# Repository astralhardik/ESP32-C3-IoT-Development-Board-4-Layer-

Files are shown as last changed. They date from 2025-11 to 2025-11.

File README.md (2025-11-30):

# ESP32-C3 IoT Development Board (4-Layer)



## 📋 Project Overview

This repository contains the hardware design files (KiCad) for a custom **4-layer IoT Development Board** powered by the **ESP32-C3-WROOM-02** module. 

Designed this compact board is an all-in-one solution for environmental sensing and data logging. It integrates power management for LiPo batteries, a suite of sensors (Environmental, Light, Audio), and dual storage options (SD Card + External Flash), making it ideal for low-power edge computing applications.

<p align="center">
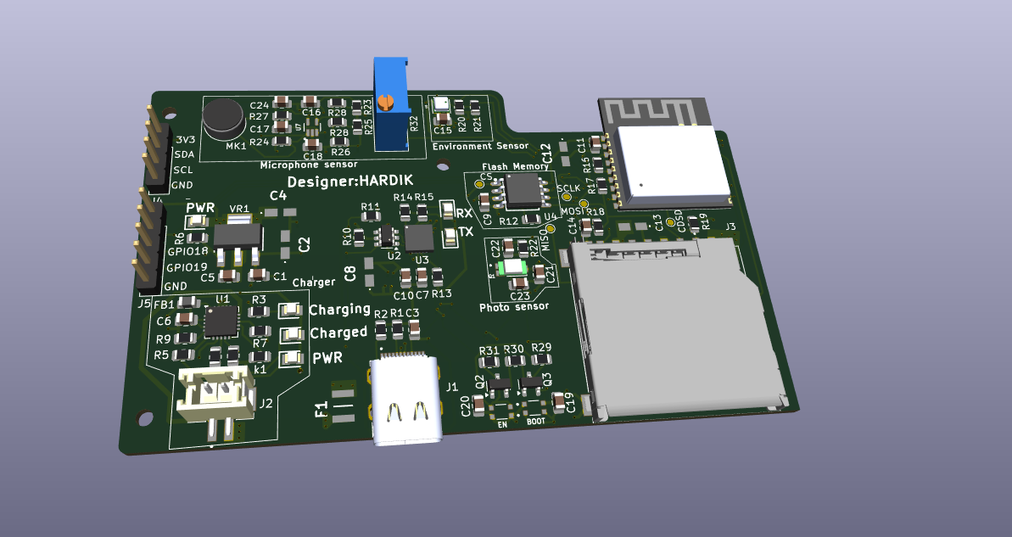
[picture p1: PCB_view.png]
3D Board View
  
</p>

## ✨ Key Features

*   **Microcontroller**: ESP32-C3-WROOM-02 (RISC-V 32-bit, WiFi 4 + Bluetooth 5 LE).
*   **4-Layer PCB**: Optimized stack-up for signal integrity and compact routing.
*   **Power System**: 
    *   **USB-C** for power and programming.
    *   **MCP73871** Li-Ion/Li-Poly Battery Charger with System Load Sharing (allows simultaneous charging and system operation).
    *   **LM1117-3.3** LDO for stable 3.3V regulation.
*   **Onboard Sensors**:
    *   **BME280**: Temperature, Humidity, and Barometric Pressure (I2C).
    *   **MAX4466**: Electret Microphone with Preamplifier (Analog Output).
    *   **TEMT6000**: Ambient Light Sensor (Analog Photo-transistor).
*   **Storage**:
    *   **MicroSD Card Slot** (SPI mode).
    *   **W25Q32** 32M-bit (4MB) External SPI Flash for logging/OTA.
*   **Connectivity**:
    *   **CP2102N** USB-to-UART Bridge with Auto-Program/Reset circuit (DTR/RTS logic).
    *   **I2C Header**: JST/Pin header for external OLED displays or sensors.

## 🔧 Hardware Specifications

| Component | Part Number | Interface | Description |
|---|---|---|---|
| **MCU Module** | ESP32-C3-WROOM-02-H4 | UART/SPI/I2C | Core processor, 4MB integrated flash |
| **USB Bridge** | CP2102N | USB 2.0 | USB to Serial converter |
| **Env. Sensor** | BME280 | I2C (Add: 0x76) | Precision Temp/Hum/Press |
| **Audio Amp** | MAX4466 | Analog (ADC) | Mic preamp with adjustable gain |
| **Light Sensor** | TEMT6000 | Analog (ADC) | Visible light spectrum sensor |
| **Charger** | MCP73871 | - | 1A Battery charger with Power Path |
| **Ext. Flash** | W25Q32JV | SPI | Additional 32Mbit storage |

## 🔌 Pinout & Interfaces

### User Interface (UI)
*   **Boot Button (SW1)**: Connected to GPIO9 (Strapping pin).
*   **Reset Button (SW2)**: Connected to EN (Enable).
*   **LED Indicators**: 
    *   Charging (Red)
    *   Charged (Green)
    *   Power/User (Blue)

### Expansion Headers
*   **J4 (I2C)**: `3V3`, `SDA`, `SCL`, `GND` - Designed for 0.96" OLED displays.
*   **J5 (GPIO)**: Breakout for spare GPIOs (GPIO8, GPIO18, GPIO19).

## 🛠️ Schematics

### Power Management
The power stage uses the **MCP73871** to manage USB and Battery power seamlessy. An **LM1117-3.3** provides the system voltage.

### Sensor Array
The board features a BME280 for environment data, a MAX4466 for audio processing, and a TEMT6000 for light detection.

### MCU & Storage
The ESP32-C3 is the heart of the board, interfacing with the SD Card and Flash memory via SPI.

## 🚀 Getting Started

1.  **Clone the repository**:
    ```
    git clone https://github.com/yourusername/ESP32-C3-IoT-Board.git
    ```
2.  **Open the Hardware Design**:
    *   Install [KiCad 9.0+](https://www.kicad.org/).
    *   Open `ESP32 project/ESP32 project.kicad_pro`.
3.  **Firmware Development**:
    *   The board uses the **CP2102N** bridge. Ensure drivers are installed.
    *   **PlatformIO / Arduino IDE**: Select board **"ESP32C3 Dev Module"**.
    *   **Auto-Upload**: The board includes the standard transistor reset logic, so no manual button pressing is required to upload code.

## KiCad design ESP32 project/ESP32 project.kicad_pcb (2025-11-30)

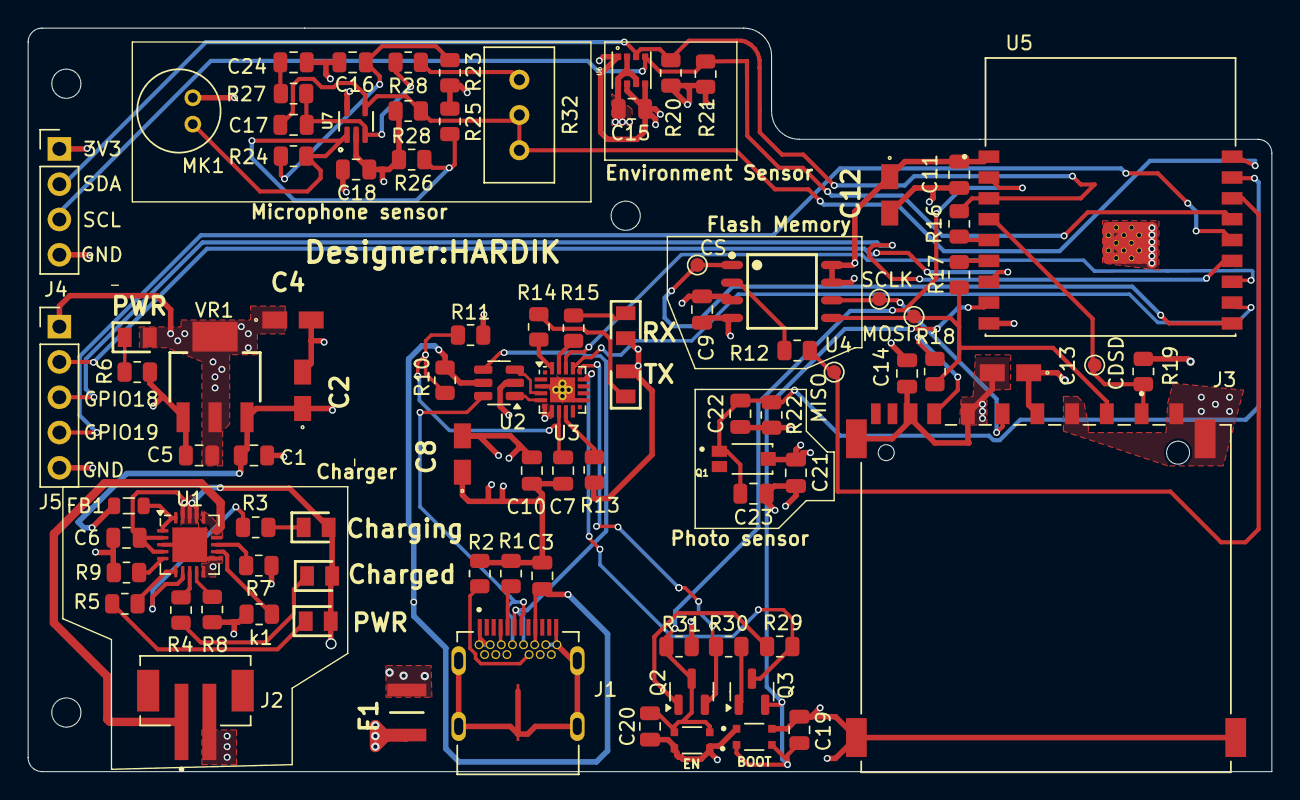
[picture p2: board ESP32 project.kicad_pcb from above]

Board: 4 copper layers, 89.5 x 53.5 mm, 90 parts (0 on the bottom side), 60 nets.

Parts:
BOOT: Boot; SW_USLPT2819DT2TR
C1, C3, C5, C10, C15, C16, C17, C18, C19, C21: 0.1u; C_0805_2012Metric
C2, C4: 10u; T491A
C6, C20: 1u; C_0805_2012Metric
C7: 1uf; C_0805_2012Metric
C8: 4.7u; T491A
C9, C11, C14: 0.1U; C_0805_2012Metric
C12, C13: 10U; T491A
C22, C23: 10n; C_0805_2012Metric
C24: 10u; C_0805_2012Metric
CDSD: Test CS_SD; TestPoint_Pad_D1.0mm
CS: Test CS; TestPoint_Pad_D1.0mm
Charged: LTST-C170GKT; LEDC2012X120N
Charging: LTST-C170TBKT; LEDC2012X120N
EN: Reset; SW_USLPT2819DT2TR
F1: 0ZCH0110AF2E; FUSC3226X100N
FB1: FerriteBead; L_0805_2012Metric
J1: SS-52400-002; BELFUSE_SS-52400-002
J2: B2B-PH-SM4-TB; JST_B2B-PH-SM4-TB
J3: GSD090012SEU; AMPHENOL_GSD090012SEU
J4: Conn_01x04_Pin; PinHeader_1x04_P2.54mm_Vertical
J5: Conn_01x05_Pin; PinHeader_1x05_P2.54mm_Vertical
MISO: Test MISO; TestPoint_Pad_D1.0mm
MK1: CMC-5042PF-AC; CUI_CMC-5042PF-AC
MOSI: Test MOSI; TestPoint_Pad_D1.0mm
PWR: LTST-C170KRKT; LEDC2012X120N
PWR#2: LTST-C170KRKT; LEDC2012X120N
Q1: TEMT6000X01; TRANS_TEMT6000X01
Q2, Q3: BC817; SOT-23
R1, R2: 5k1; R_0805_2012Metric
R3, R4, R5, R6, R14, R15: 470; R_0805_2012Metric
R7: 2k; R_0805_2012Metric
R8, R9, R22: 10k; R_0805_2012Metric
R10: 22k1; R_0805_2012Metric
R11: 47k5; R_0805_2012Metric
R12, R16, R17, R18: 50; R_0805_2012Metric
R13, R27: 1k; R_0805_2012Metric
R19, R29, R30, R31: 10K; R_0805_2012Metric
R20, R21: 4k7; R_0805_2012Metric
R23, R24: 2K; R_0805_2012Metric
R25, R26: 1M; R_0805_2012Metric
R28: 100K; R_0805_2012Metric
R28#2: 22k; R_0805_2012Metric
R32: 35WR100KLFTR; Potentiometer_Bourns_3296W_Vertical
RX: LTST-C170KRKT; LEDC2012X120N
SCLK: Test SCLK; TestPoint_Pad_D1.0mm
TX: LTST-C170GKT; LEDC2012X120N
U1: MCP73871; QFN-20-1EP_4x4mm_P0.5mm_EP2.5x2.5mm
U2: USBLC6-2SC6; SOT-23-6
U3: CP2102N-Axx-xQFN20; SiliconLabs_QFN-20-1EP_3x3mm_P0.5mm_EP1.8x1.8mm_ThermalVias
U4: W25Q32JVSSIQ; SOIC127P790X216-8N
U5: ESP32-C3-WROOM-02-H4; MODULE_ESP32-C3-WROOM-02-H4
U6: BME280; PSON65P250X250X100-8N
U7: MAX4466EXK; SOT65P210X110-5N
VR1: LM1117MPX-3.3; VREG_LM1117MPX-3.3
k1: 20k; R_0805_2012Metric

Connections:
+3.3V: C4.1, C5.1, C8.2, C9.1, C10.2, C11.1, C12.1, C13.1, C14.1, C15.1, C18.1, C21.2, J3.4 (VDD1), J4.1, J5.1, PWR#2.2 (A), Q1.3, R13.1, R19.1, R20.1, R21.1, R23.1, R25.1, R31.1, RX.2 (A), TX.2 (A), U3.6 (VDD), U3.7 (VREGIN), U4.3 (~WP(IO2)), U4.7 (~HOLD/~RESET(IO3)), U4.8 (VCC), U5.1 (3V3), U6.2 (CSB), U6.6 (VDDIO), U6.8 (VDD), U7.5 (VCC), VR1.2 (VOUT_2), VR1.4 (VOUT_4)
+5V: C1.1, C2.1, FB1.2, VR1.3 (VIN)
/+5v_USB: C6.1, Charged.2 (A), Charging.2 (A), F1.2, PWR.2 (A), U1.2 (VPCC), U1.4 (PROG2), U1.17 (CE), U1.18 (IN), U1.19 (IN)
/ESP32-C3-02/BOOT: BOOT.3 (B0), BOOT.4 (B1), C19.1, Q3.2 (E), U5.8 (IO9)
/ESP32-C3-02/CD_SD: CDSD.1, J3.1 (CD/DAT3), R19.2, U5.4 (IO5)
/ESP32-C3-02/CS: CS.1, U4.1 (~CS), U5.10 (IO10)
/ESP32-C3-02/CTS: Q3.3 (C), R29.1, U3.15 (~CTS)
/ESP32-C3-02/EN: C20.1, EN.3 (B0), EN.4 (B1), Q2.3 (C), R31.2, U5.2 (EN)
/ESP32-C3-02/GPIO8: J5.2, U5.7 (IO8)
/ESP32-C3-02/GPIO18: J5.3, U5.13 (IO18)
/ESP32-C3-02/GPIO19: J5.4, U5.14 (IO19)
/ESP32-C3-02/MIC_OUT: C17.2, R28.2, R32.1, R32.2, U5.18 (IO0), U7.4 (OUT)
/ESP32-C3-02/MISO_DO: MISO.1, R12.2, U5.16 (IO2)
/ESP32-C3-02/MOSI_DI: J3.2 (CMD), MOSI.1, R17.1, R18.1, U4.5 (DI(IO0))
/ESP32-C3-02/PHOTO_C: C22.1, C23.1, Q1.1, R22.1, U5.17 (IO1)
/ESP32-C3-02/RTS: Q2.2 (E), R30.1, U3.16 (~RTS)
/ESP32-C3-02/RX_TX: U3.17 (RXD), U5.11 (RXD)
/ESP32-C3-02/SCL: J4.3, R21.2, U5.15 (IO3), U6.4 (SCK)
/ESP32-C3-02/SCLK: J3.5 (CLK), SCLK.1, U4.6 (CLK)
/ESP32-C3-02/SDA: J4.2, R16.1, R20.2, U5.3 (IO4), U6.3 (SDI)
/ESP32-C3-02/TX_RX: U3.18 (TXD), U5.12 (TXD)
/ESP32-C3-02/USB_D+: U2.3 (I/O2), U3.4 (D+)
/ESP32-C3-02/USB_D-: U2.1 (I/O1), U3.5 (D-)
/USB_DN: J1.A7 (DN1), J1.B7 (DN2), U2.6 (I/O1)
/USB_DP: J1.A6 (DP1), J1.B6 (DP2), U2.4 (I/O2)
/VBAT: J2.1, U1.14 (V_{BAT}), U1.15 (V_{BAT}), U1.16 (V_{BAT_SENSE})
/vBUS: C3.1, F1.1, J1.A4 (VBUSA1), J1.A9 (VBUSA2), J1.B4 (VBUSB1), J1.B9 (VBUSB2), R10.1, U2.5 (VBUS)
GND: BOOT.1 (A0), BOOT.2 (A1), C1.2, C2.2, C3.2, C4.2, C5.2, C6.2, C7.2, C8.1, C9.2, C10.1, C11.2, C12.2, C13.2, C14.2, C15.2, C16.1, C18.2, C19.2, C20.2, C21.1, C22.2, C23.2, C24.1, EN.1 (A0), EN.2 (A1), J1.A1 (GNDA1), J1.A12 (GNDA2), J1.B1 (GNDB1), J1.B12 (GNDB2), J1.G1 (GND/SHIELD), J1.G2 (GND/SHIELD), J1.G3 (GND/SHIELD), J1.G4 (GND/SHIELD), J1.S1 (GND/SHIELD), J1.S2 (GND/SHIELD), J1.S3 (GND/SHIELD), J1.S4 (GND/SHIELD), J2.2, J3.3 (VSS1), J3.6 (VSS2), J3.8 (DAT1), J3.9 (DAT2), J3.G1 (SHIELD_GND), J3.G2 (SHIELD_GND), J3.G3 (SHIELD_GND), J3.G4 (SHIELD_GND), J4.4, J5.5, MK1.GND, R1.2, R2.2, R6.2, R7.1, R8.2, R9.1, R11.2, R22.2, R26.2, R28.1, U1.3 (SEL), U1.10 (V_{SS}), U1.11 (V_{SS}), U1.21 (V_{SS}), U2.2 (GND), U4.4 (GND), U5.9 (GND), U5.19 (GND), U5.20 (GND), U5.21 (GND), U5.22 (GND), U5.23 (GND), U5.24 (GND), U5.25 (GND), U5.26 (GND), U5.27 (GND), U5.28 (GND), U5.29 (GND), U5.30 (GND), U5.31 (GND), U5.32 (GND), U5.33 (GND), U5.34 (GND), U5.35 (GND), U5.36 (GND), U5.37 (GND), U5.38 (GND), U5.39 (GND), U6.1 (GND), U6.5 (SDO), U6.7 (GND), U7.2 (GND), VR1.1 (GND), k1.1
unnamed: C16.2, R23.2, R24.1
unnamed: C24.2, R27.1
unnamed: FB1.1, U1.1 (OUT), U1.20 (OUT)
unnamed: J1.A5 (CC1), R1.1
unnamed: J1.B5 (CC2), R2.1
unnamed: J3.7 (DAT0), R18.2
unnamed: Charging.1 (K), R3.1
unnamed: PWR#2.1 (K), R6.1
unnamed: Charged.1 (K), R4.1
unnamed: PWR.1 (K), R5.1
unnamed: R14.1, TX.1 (K)
unnamed: R15.1, RX.1 (K)
unnamed: Q2.1 (B), R29.2
unnamed: Q3.1 (B), R30.2
unnamed: R28#2.1, R32.3
unnamed: R7.2, U1.13 (PROG1)
unnamed: U1.12 (PROG3), k1.2
unnamed: R4.2, U1.8 (STAT1/~LBO)
unnamed: R3.2, U1.7 (STAT2)
unnamed: R9.2, U1.5 (THERM)
unnamed: R5.2, U1.6 (~PG)
unnamed: R8.1, U1.9 (~TE)
unnamed: U3.3 (GND), U3.12 (GND), U3.21 (GND)
unnamed: C7.1, R10.2, R11.1, U3.8 (VBUS)
unnamed: R13.2, U3.9 (~RST)
unnamed: R15.2, U3.19 (~RXT/GPIO.3)
unnamed: R14.2, U3.20 (~TXT/GPIO.2)
unnamed: R12.1, U4.2 (DO(IO1))
unnamed: R16.2, U5.5 (IO6)
unnamed: R17.2, U5.6 (IO7)
unnamed: MK1.OUT, R24.2, R25.2, R26.1, U7.1 (IN+)
unnamed: C17.1, R27.2, R28#2.2, U7.3 (IN-)

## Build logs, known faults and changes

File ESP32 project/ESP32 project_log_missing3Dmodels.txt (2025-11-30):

[('C8', 'D:\\kicad\\ESP32-IOT 4 Layer PCB\\ESP32 project\\T491A106K010AT7280.stp'), ('LED4', 'D:\\kicad\\ESP32-IOT 4 Layer PCB\\ESP32 project\\LTST-C170KRKT.stp'), ('LED5', 'D:\\kicad\\ESP32-IOT 4 Layer PCB\\ESP32 project\\LTST-C170KRKT.stp'), ('LED1', 'D:\\kicad\\ESP32-IOT 4 Layer PCB\\ESP32 project\\LTST-C170KRKT.stp'), ('U3', 'D:\\kicad\\share\\kicad\\3dmodels\\Package_DFN_QFN.3dshapes\\SiliconLabs_QFN-20-1EP_3x3mm_P0.5mm_EP1.8x1.8mm.step'), ('LED2', 'D:\\kicad\\ESP32-IOT 4 Layer PCB\\ESP32 project\\LTST-C170KRKT.stp'), ('F1', 'D:\\kicad\\ESP32-IOT 4 Layer PCB\\ESP32 project\\0ZCH0110AF2E.stp'), ('C4', 'D:\\kicad\\ESP32-IOT 4 Layer PCB\\ESP32 project\\T491A106K010AT7280.stp'), ('LED3', 'D:\\kicad\\ESP32-IOT 4 Layer PCB\\ESP32 project\\LTST-C170KRKT.stp'), ('LED6', 'D:\\kicad\\ESP32-IOT 4 Layer PCB\\ESP32 project\\LTST-C170KRKT.stp'), ('C13', 'D:\\kicad\\ESP32-IOT 4 Layer PCB\\ESP32 project\\T491A106K010AT7280.stp'), ('C2', 'D:\\kicad\\ESP32-IOT 4 Layer PCB\\ESP32 project\\T491A106K010AT7280.stp'), ('C12', 'D:\\kicad\\ESP32-IOT 4 Layer PCB\\ESP32 project\\T491A106K010AT7280.stp')]

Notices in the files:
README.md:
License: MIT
